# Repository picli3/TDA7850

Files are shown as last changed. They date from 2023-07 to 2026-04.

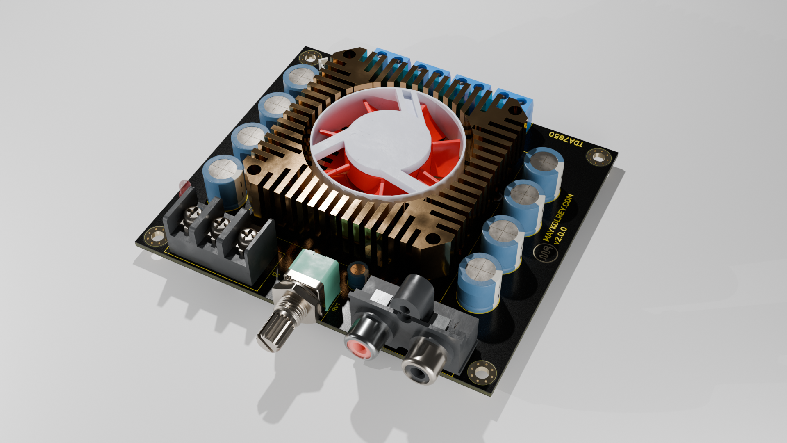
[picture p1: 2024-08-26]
iso.png

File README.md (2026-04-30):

# TDA7850

Amplificador de audio basado en el **TDA7850**, orientado a una solución multicanal o de alta integración usando un circuito integrado dedicado para audio.

## Propósito del proyecto
Este proyecto busca concentrar en una sola PCB una etapa de amplificación basada en TDA7850, útil para aplicaciones de audio automotriz, doméstico compacto o prototipos multicanal.

## Qué incluye
- esquemático del amplificador
- diseño PCB en KiCad
- base práctica para pruebas y fabricación de una etapa de audio integrada

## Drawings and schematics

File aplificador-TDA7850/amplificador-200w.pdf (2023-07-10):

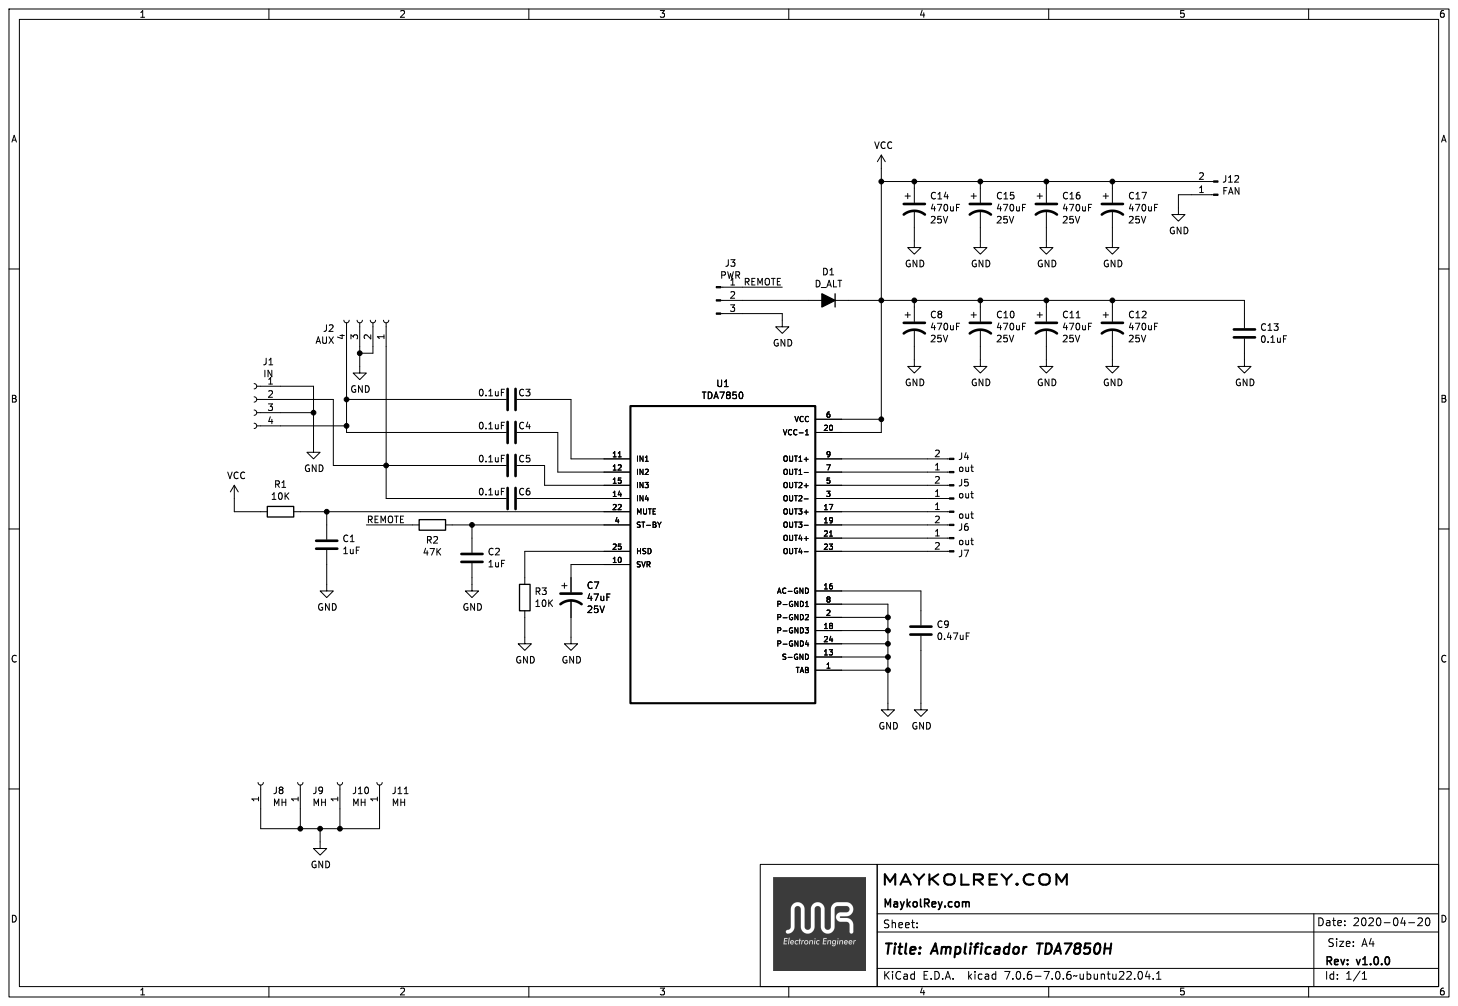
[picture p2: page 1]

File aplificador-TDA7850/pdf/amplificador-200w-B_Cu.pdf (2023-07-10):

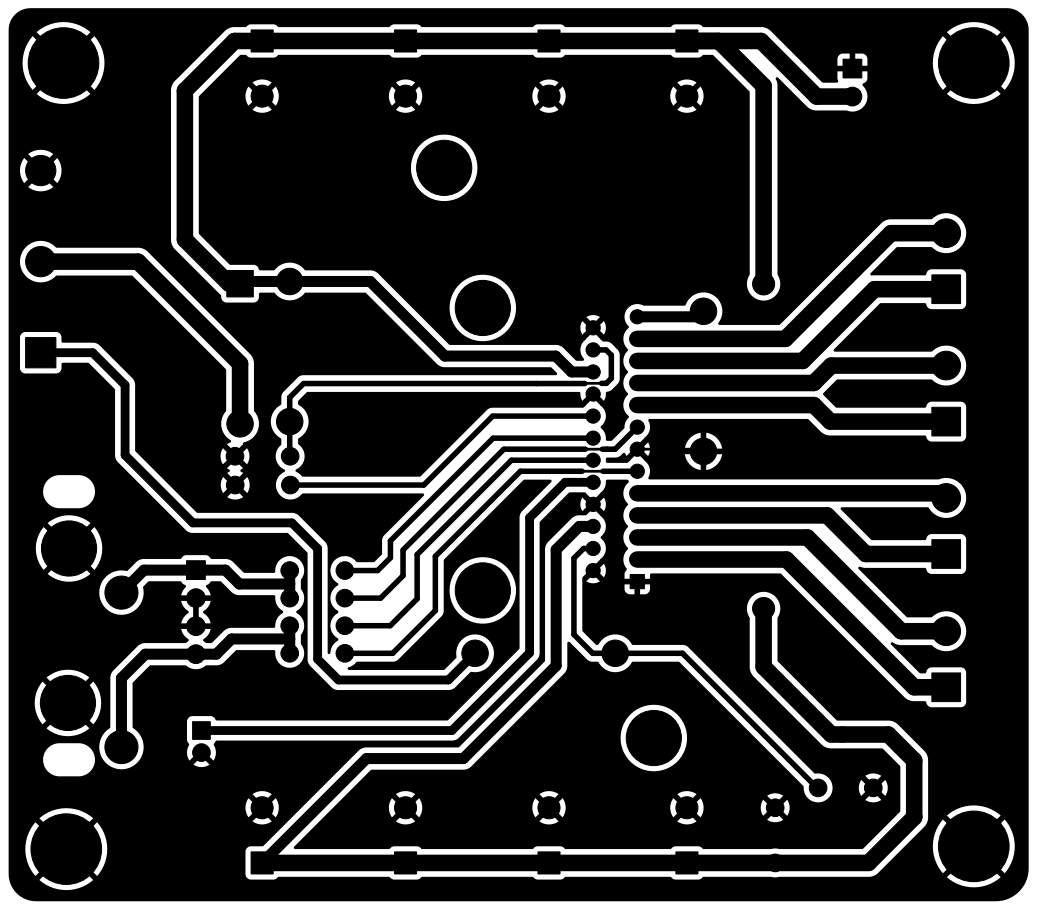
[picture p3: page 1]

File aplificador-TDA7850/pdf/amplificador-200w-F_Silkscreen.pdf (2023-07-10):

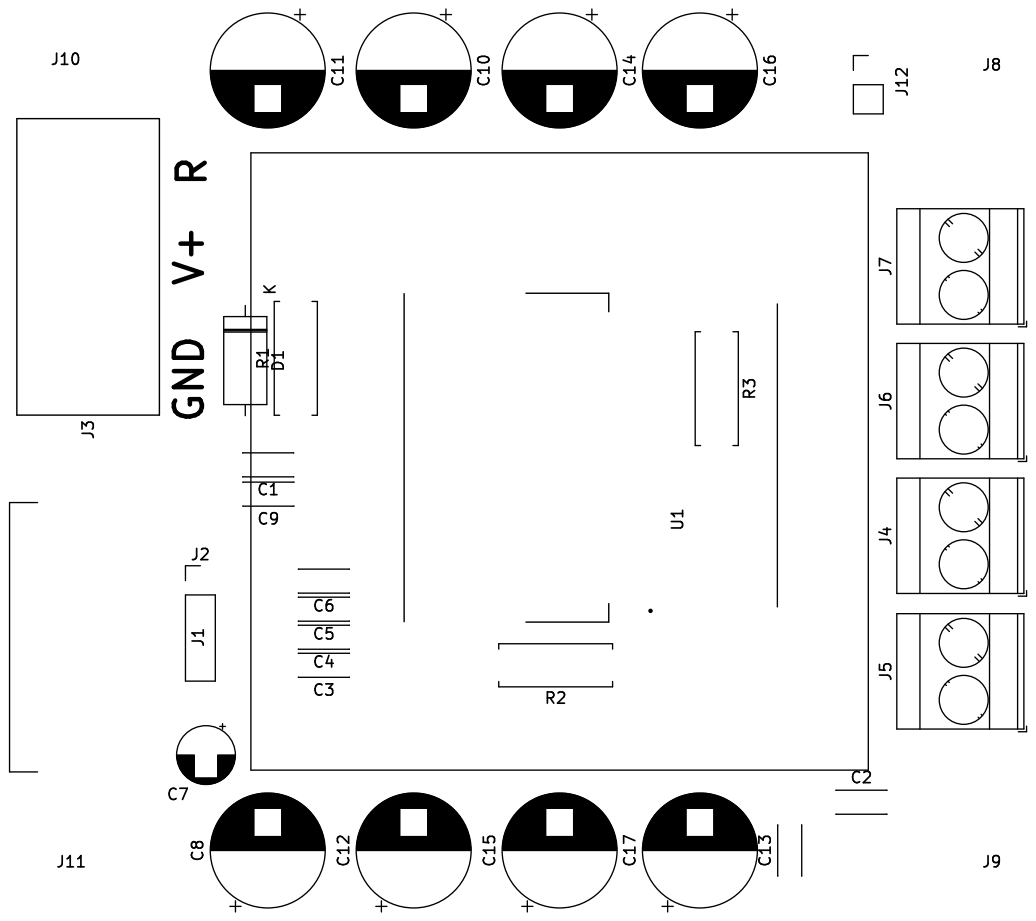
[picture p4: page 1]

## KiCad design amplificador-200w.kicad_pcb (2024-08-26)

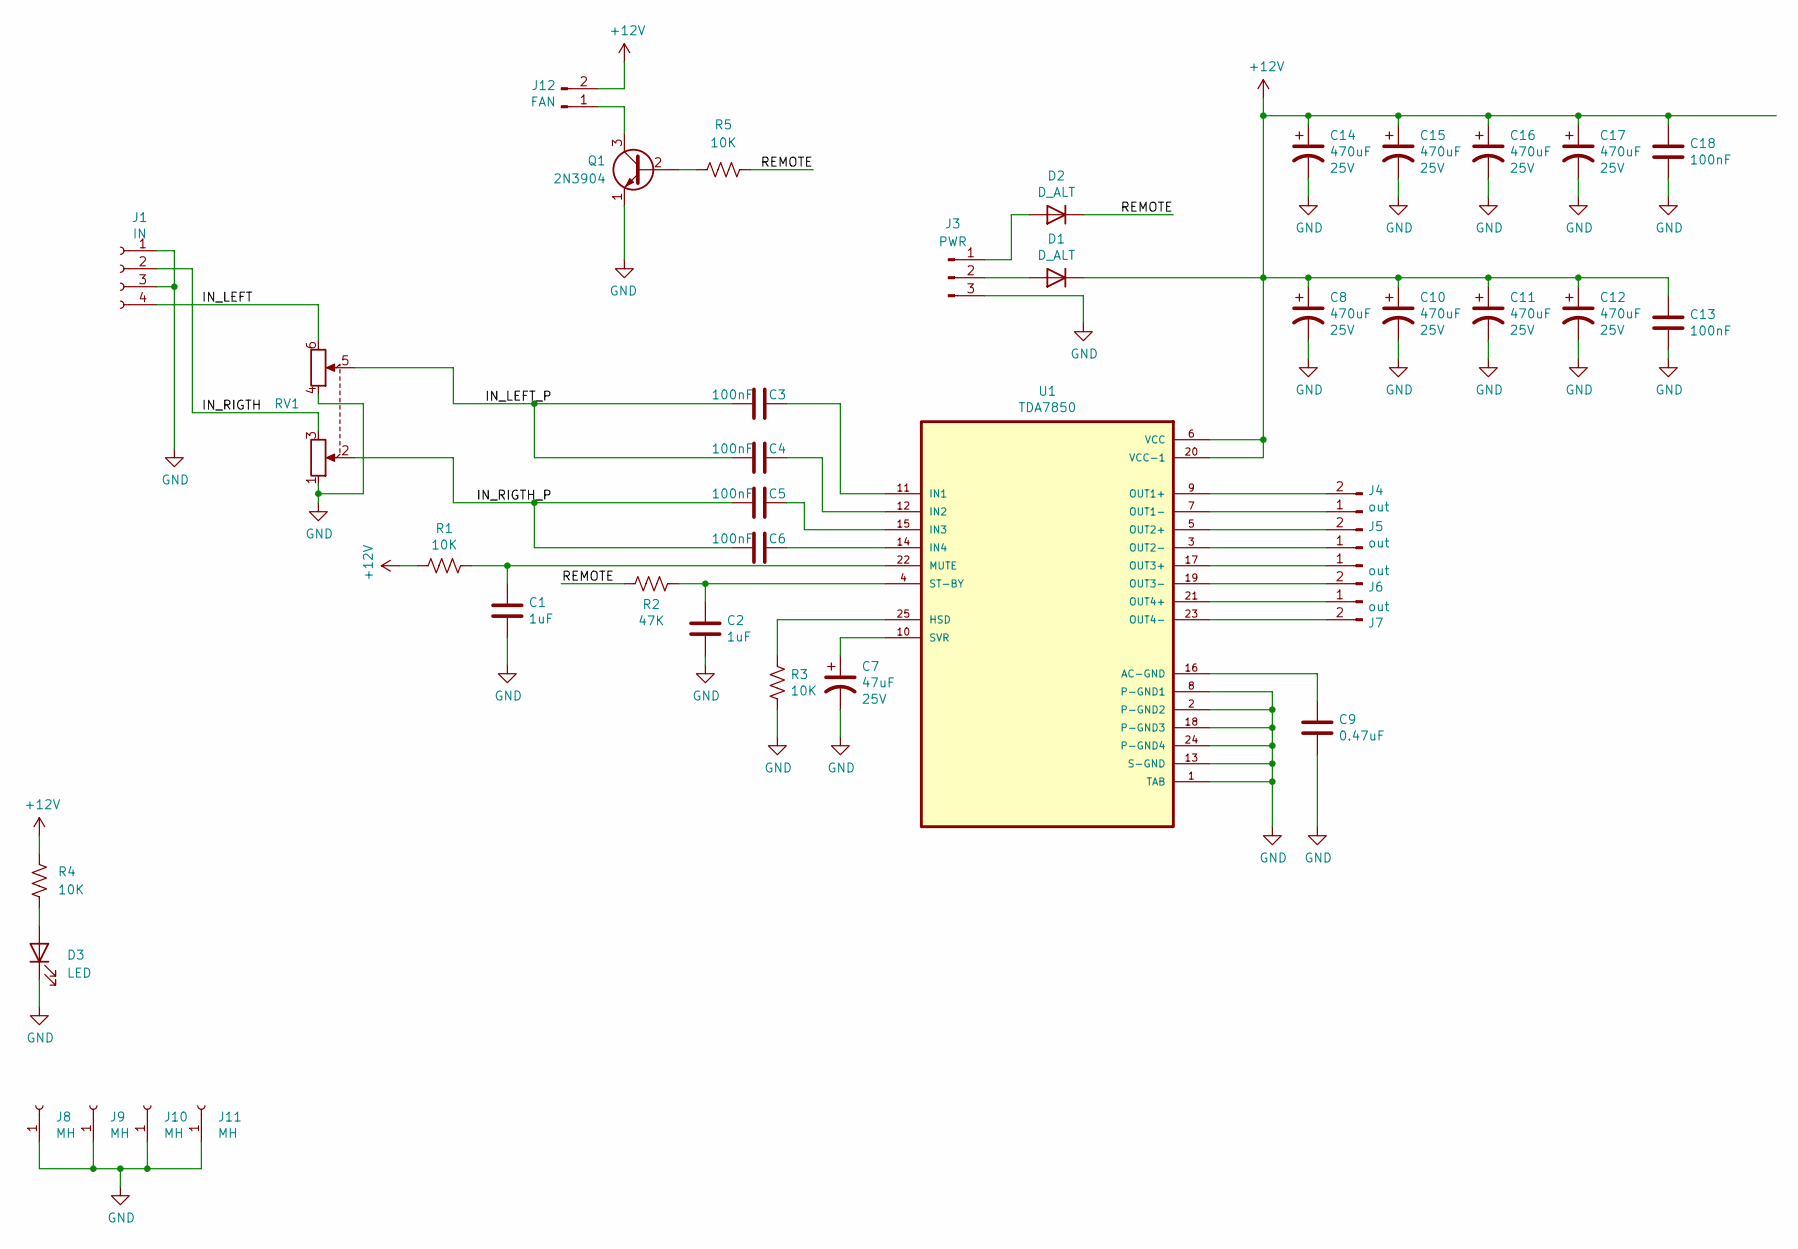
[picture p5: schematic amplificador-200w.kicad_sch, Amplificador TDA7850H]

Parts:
C1, C2: 1uF; C_0805_2012Metric
C3, C4, C5, C6, C13, C18: 100nF; C_0603_1608Metric_Pad1.08x0.95mm_HandSolder
C7: 47uF; CP_Radial_D5.0mm_P2.00mm
C8, C10, C11, C12, C14, C15, C16, C17: 470uF; CP_Radial_D10.0mm_P5.00mm
C9: 0.47uF; C_0603_1608Metric_Pad1.08x0.95mm_HandSolder
D1, D2: D_ALT; D_SMA
D3: LED; LED_D3.0mm
J1: IN; CUI_RCJ-21XX; Mfg Part # RCJ-2121
J3: PWR; TE_2-1437667-5; Mfg Part # OSTYK42103030
J4, J5, J6, J7: out; TerminalBlock_Phoenix_MKDS-3-2-5.08_1x02_P5.08mm_Horizontal
J8, J9, J10, J11: MH; MountingHole_3.2mm_M3_Pad_Via
J12: FAN; JST_PH_B2B-PH-K_1x02_P2.00mm_Vertical
Q1: 2N3904; TO-92_Inline
R1, R3, R4, R5: 10K; R_0603_1608Metric
R2: 47K; R_0603_1608Metric
RV1: R_Potentiometer_Dual; Potentiometer_Alps_RK097_Dual_Horizontal
U1: TDA7850; TDA7850H

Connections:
+12V: C8.1, C10.1, C11.1, C12.1, C13.1, C14.1, C15.1, C16.1, C17.1, C18.1, D1.1 (K), J12.2, R1.2, R4.1, U1.6 (VCC), U1.20 (VCC-1)
/IN_LEFT: J1.4, RV1.6
/IN_LEFT_P: C3.2, C4.2, RV1.5
/IN_RIGTH: J1.2, RV1.3
/IN_RIGTH_P: C5.2, C6.2, RV1.2
/REMOTE: D2.1 (K), R2.2, R5.2
GND: C1.2, C2.2, C7.2, C8.2, C9.2, C10.2, C11.2, C12.2, C13.2, C14.2, C15.2, C16.2, C17.2, C18.2, D3.1 (K), J1.1, J1.3, J3.3, J8.1, J9.1, J10.1, J11.1, Q1.1 (E), R3.2, RV1.1, RV1.4, U1.1 (TAB), U1.2 (P-GND2), U1.8 (P-GND1), U1.13 (S-GND), U1.18 (P-GND3), U1.24 (P-GND4)
unnamed: D1.2 (A), J3.2
unnamed: D2.2 (A), J3.1
unnamed: D3.2 (A), R4.2
unnamed: J4.1, U1.7 (OUT1-)
unnamed: J4.2, U1.9 (OUT1+)
unnamed: J5.1, U1.3 (OUT2-)
unnamed: J5.2, U1.5 (OUT2+)
unnamed: J6.1, U1.17 (OUT3+)
unnamed: J6.2, U1.19 (OUT3-)
unnamed: J7.1, U1.21 (OUT4+)
unnamed: J7.2, U1.23 (OUT4-)
unnamed: J12.1, Q1.3 (C)
unnamed: Q1.2 (B), R5.1
unnamed: C9.1, U1.16 (AC-GND)
unnamed: R3.1, U1.25 (HSD)
unnamed: C3.1, U1.11 (IN1)
unnamed: C4.1, U1.12 (IN2)
unnamed: C5.1, U1.15 (IN3)
unnamed: C6.1, U1.14 (IN4)
unnamed: C1.1, R1.1, U1.22 (MUTE)
unnamed: C2.1, R2.1, U1.4 (ST-BY)
unnamed: C7.1, U1.10 (SVR)

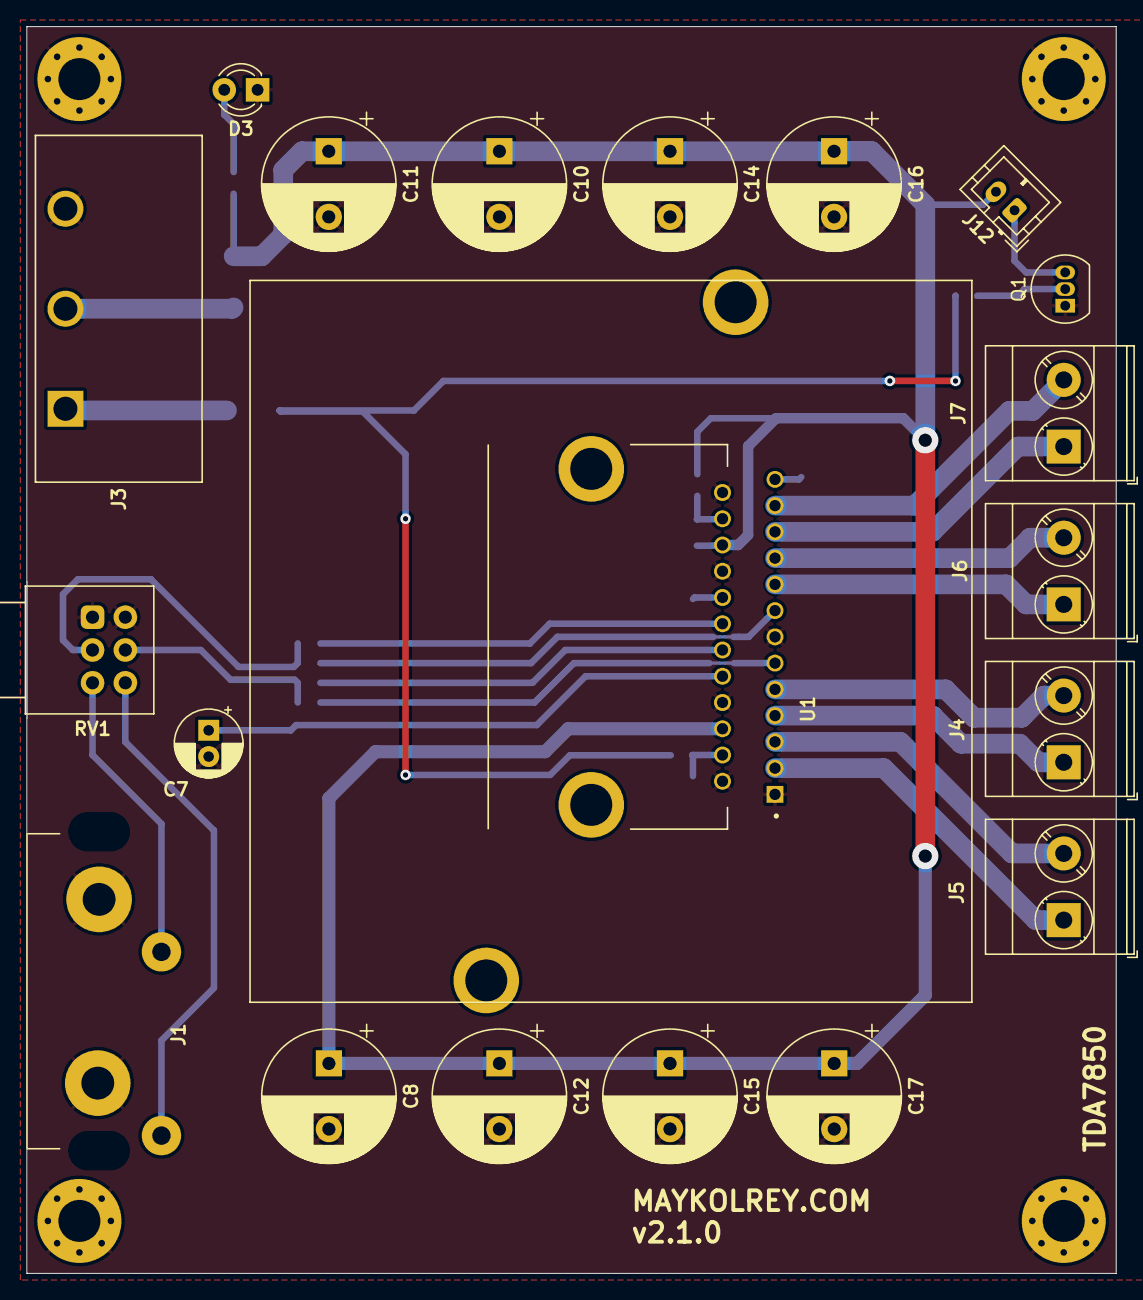
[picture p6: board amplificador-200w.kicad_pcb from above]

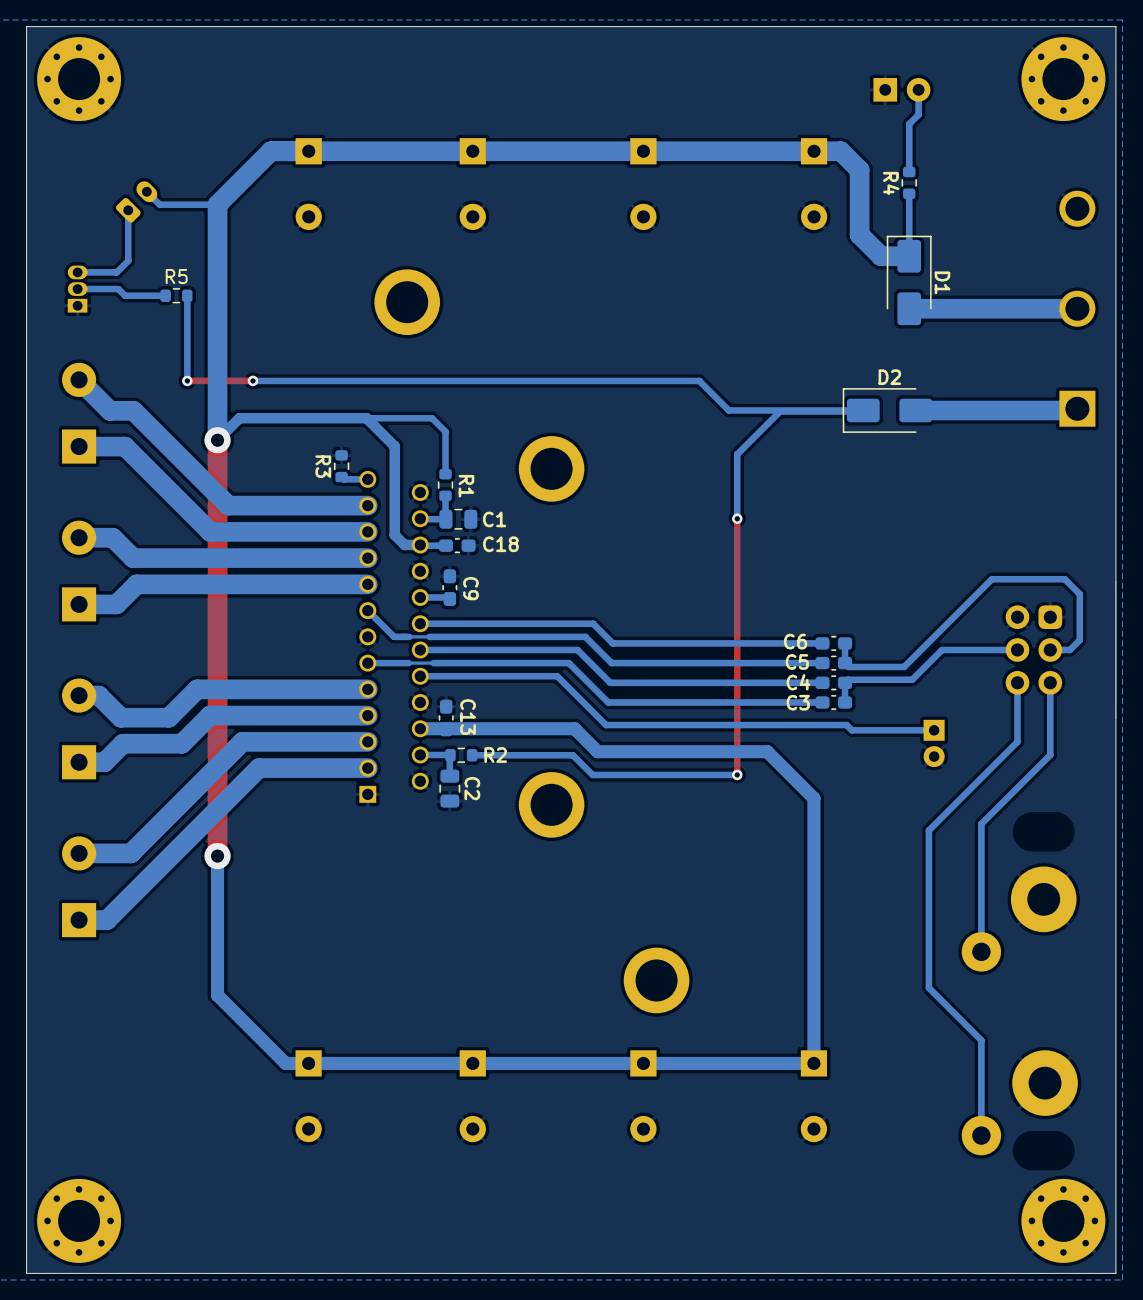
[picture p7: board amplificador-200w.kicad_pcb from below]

Board: 2 copper layers, 83.0 x 95.0 mm, 40 parts (16 on the bottom side), 29 nets.

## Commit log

2020-09-05 listo para producir
    [BOM-amplificador-200w.xlsx, amplificador-200w.csv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]
2023-07-10 actualizando circuito
    [BOM-amplificador-200w.xlsx, amplificador-200w.csv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]
2023-07-10 borrando csv
    [amplificador-200w.csv]
2023-07-10 agregando pdf para metodo planchado
2023-07-29 quitando la entrada de audio auxiliar
    [amplificador-200w.kicad_pcb, amplificador-200w.kicad_sch]
2024-07-21 version 2 enviada a fabricar
    [amplificador-200w.kicad_pcb, amplificador-200w.kicad_sch]
2024-08-26 corrgiendo disipador y que el ventilador solo prenda con remote
    [amplificador-200w.kicad_pcb, amplificador-200w.kicad_sch]
